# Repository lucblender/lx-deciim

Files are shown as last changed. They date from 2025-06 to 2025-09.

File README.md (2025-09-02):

# lx-deciim

lx-deciim

The lx-deciim is a unique 2-channel bitcrusher eurorack module. Conventionals bitcrushers reduce resolution of the input bit by bit starting by the LSB (Least Significant Bit).

The lx-deciim let you select which bit you want to disable. In addition, when a bit is disabled, it can be replaced by a CV input going through a trigger to get a clean '0' '1' value.

The trigger compares the input value against the CV to a reference voltate. This ref value can be set to either 0V or 2.5V from a jumper on the back of the module. In addition, you can also downsample the input signal.

The module is based on the Daisy Seed by Electrosmith.

## Concept

The concept of the module can be described by the following equation:

`audioOut = (audioIn & ~concatSwitch) + (concatTrigger & concatSwitch)`

Considering:

- `audioOut` : 12 bits binary audio output in (integer)
- `audioIn` : 12 bits binary audio input in (integer)
- `concatSwitch` : 12 bits binary value of the concatenation of the switches' value
- `concatTrigger` : 12 bits binary value of the concatenation of the input trigger value

## Bloc diagram

Bloc diagram

## Specification

- 12 bits 48kHz
- 12 CVs input to trigger audio-rate capable
- 2 inputs eurack level compatible +-5V
- 2 outputs eurack level compatible +-5V
- Downsampling from 48kHz to 1kHz
- Width: 12HP
- Power Consumptions +12V=80mA, -12V=2mA, +5V=0mA

## Repository content

- [Hardware](Hardware/): KiCad Project & Front Panel
  - [Hardware/lx-deciim/](Hardware/lx-deciim/): KiCad Project, Main PCB + Front Panel PCB
  - [Hardware/lx-deciim-front-panel/](Hardware/lx-deciim-front-panel/): SVG design of the front panel
- [Software](Software/): Main software & python script to generate front panel design
  - [Software/lx-deciim-libdaisy/](Software/lx-deciim-libdaisy/): Main software based on LibDaisy
  - [pattern_square_generator.py](Software/pattern_square_generator.py): Main software & python script to generate front panel design

## Hardware

The module consist of 2 PCBs. The main PCB (in reality two PCBs on a panel), and the front panel. The main PCB is really standard 2 layers PCB. After snapping the panel, you can assemble the two PCBs together with the help of male/female header. The front panel is a one layer PCB. I chose matte black solder mask, white silkscreen and ENIG finish on the copper.

All PCB shown in pictures in this repo are manufactured using [PCBWay](https://pcbway.com) services.

PCBWay provides high-quality PCB manufacturing with reliable service and fast turnaround times, making them my first choice for prototyping as seen in this project. They can also make more complex PCB to fit any of your requirements.

## License

This project is licensed under the [CC BY-NC 4.0](https://creativecommons.org/licenses/by-nc/4.0/) License. You may use, modify, and share it for non-commercial purposes.

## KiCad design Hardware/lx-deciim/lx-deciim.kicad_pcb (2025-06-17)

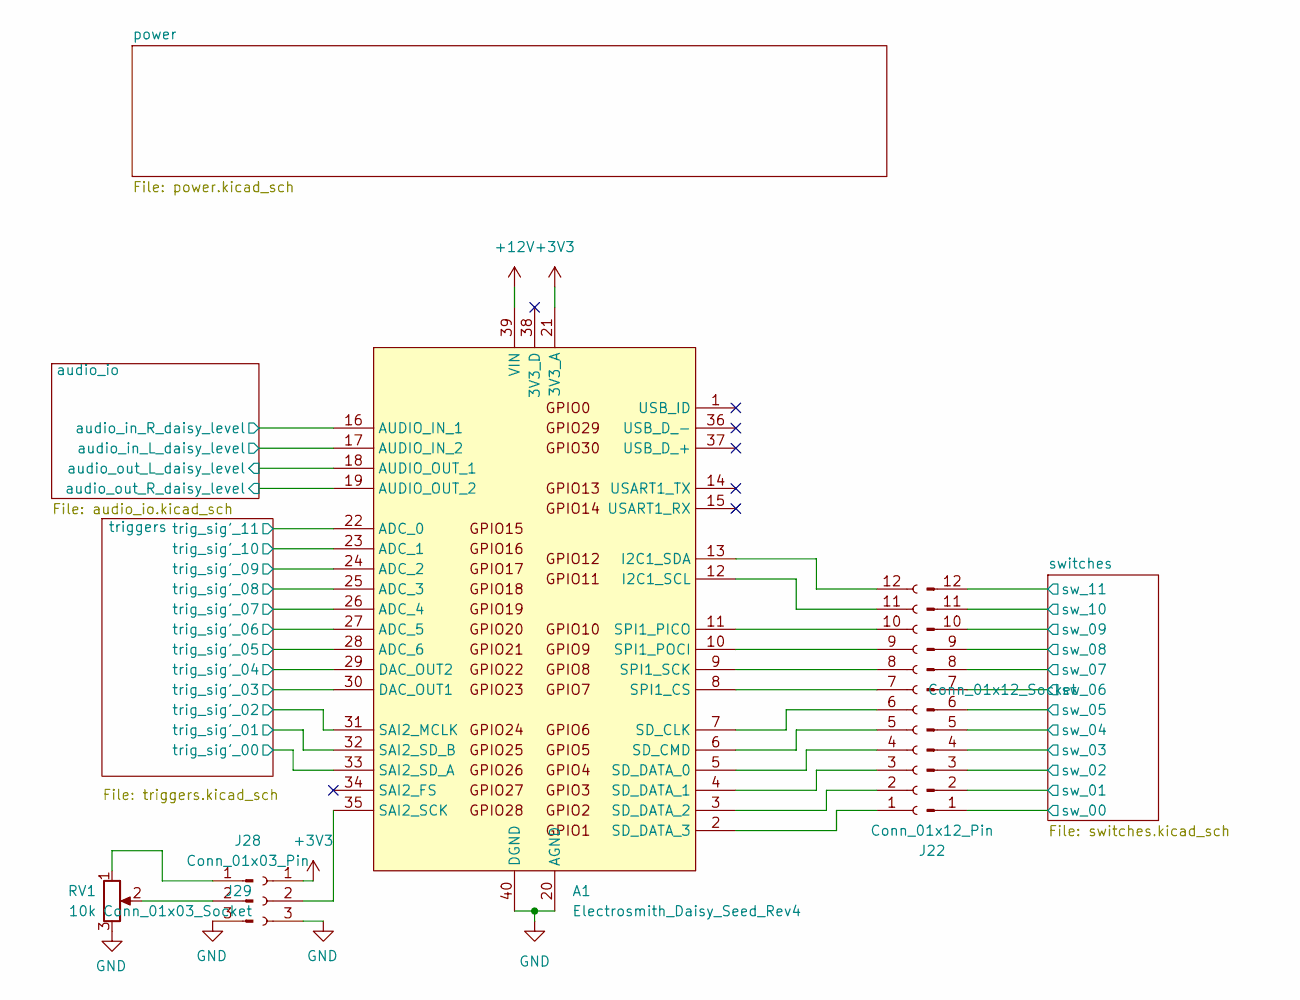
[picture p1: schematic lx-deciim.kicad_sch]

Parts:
A1: Electrosmith_Daisy_Seed_Rev4; Electrosmith_Daisy_Seed
J22: Conn_01x12_Pin; PinHeader_1x12_P2.54mm_Vertical
J23: Conn_01x12_Socket; PinSocket_1x12_P2.54mm_Vertical
J28: Conn_01x03_Pin; PinHeader_1x03_P2.54mm_Vertical
J29: Conn_01x03_Socket; PinSocket_1x03_P2.54mm_Vertical
RV1: 10k; Potentiometer_Alpha_RD901F-40-00D_Single_Vertical; Mouser Part Number 311-1940F-15F-B10K

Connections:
+3V3: A1.21 (3V3_A), J29.1
+12V: A1.39 (VIN); also elsewhere on the board
/audio_io/audio_in_L_daisy_level: A1.17 (AUDIO_IN_2); also elsewhere on the board
/audio_io/audio_in_R_daisy_level: A1.16 (AUDIO_IN_1); also elsewhere on the board
/audio_io/audio_out_L_daisy_level: A1.18 (AUDIO_OUT_1); also elsewhere on the board
/audio_io/audio_out_R_daisy_level: A1.19 (AUDIO_OUT_2); also elsewhere on the board
/switches/sw_00: J22.1; also elsewhere on the board
/switches/sw_01: J22.2; also elsewhere on the board
/switches/sw_02: J22.3; also elsewhere on the board
/switches/sw_03: J22.4; also elsewhere on the board
/switches/sw_04: J22.5; also elsewhere on the board
/switches/sw_05: J22.6; also elsewhere on the board
/switches/sw_06: J22.7; also elsewhere on the board
/switches/sw_07: J22.8; also elsewhere on the board
/switches/sw_08: J22.9; also elsewhere on the board
/switches/sw_09: J22.10; also elsewhere on the board
/switches/sw_10: J22.11; also elsewhere on the board
/switches/sw_11: J22.12; also elsewhere on the board
GND: A1.20 (AGND), A1.40 (DGND), J28.3, J29.3, RV1.3; also elsewhere on the board
unnamed: A1.12 (I2C1_SCL), J23.11
unnamed: A1.13 (I2C1_SDA), J23.12
unnamed: A1.35 (SAI2_SCK), J29.2
unnamed: A1.7 (SD_CLK), J23.6
unnamed: A1.6 (SD_CMD), J23.5
unnamed: A1.5 (SD_DATA_0), J23.4
unnamed: A1.4 (SD_DATA_1), J23.3
unnamed: A1.3 (SD_DATA_2), J23.2
unnamed: A1.2 (SD_DATA_3), J23.1
unnamed: A1.8 (SPI1_CS), J23.7
unnamed: A1.11 (SPI1_PICO), J23.10
unnamed: A1.10 (SPI1_POCI), J23.9
unnamed: A1.9 (SPI1_SCK), J23.8
unnamed: J28.1, RV1.1
unnamed: J28.2, RV1.2
trig_sig'_00: A1.33 (SAI2_SD_A); also elsewhere on the board
trig_sig'_01: A1.32 (SAI2_SD_B); also elsewhere on the board
trig_sig'_02: A1.31 (SAI2_MCLK); also elsewhere on the board
trig_sig'_03: A1.30 (DAC_OUT1); also elsewhere on the board
trig_sig'_04: A1.29 (DAC_OUT2); also elsewhere on the board
trig_sig'_05: A1.28 (ADC_6); also elsewhere on the board
trig_sig'_06: A1.27 (ADC_5); also elsewhere on the board
trig_sig'_07: A1.26 (ADC_4); also elsewhere on the board
trig_sig'_08: A1.25 (ADC_3); also elsewhere on the board
trig_sig'_09: A1.24 (ADC_2); also elsewhere on the board
trig_sig'_10: A1.23 (ADC_1); also elsewhere on the board
trig_sig'_11: A1.22 (ADC_0); also elsewhere on the board

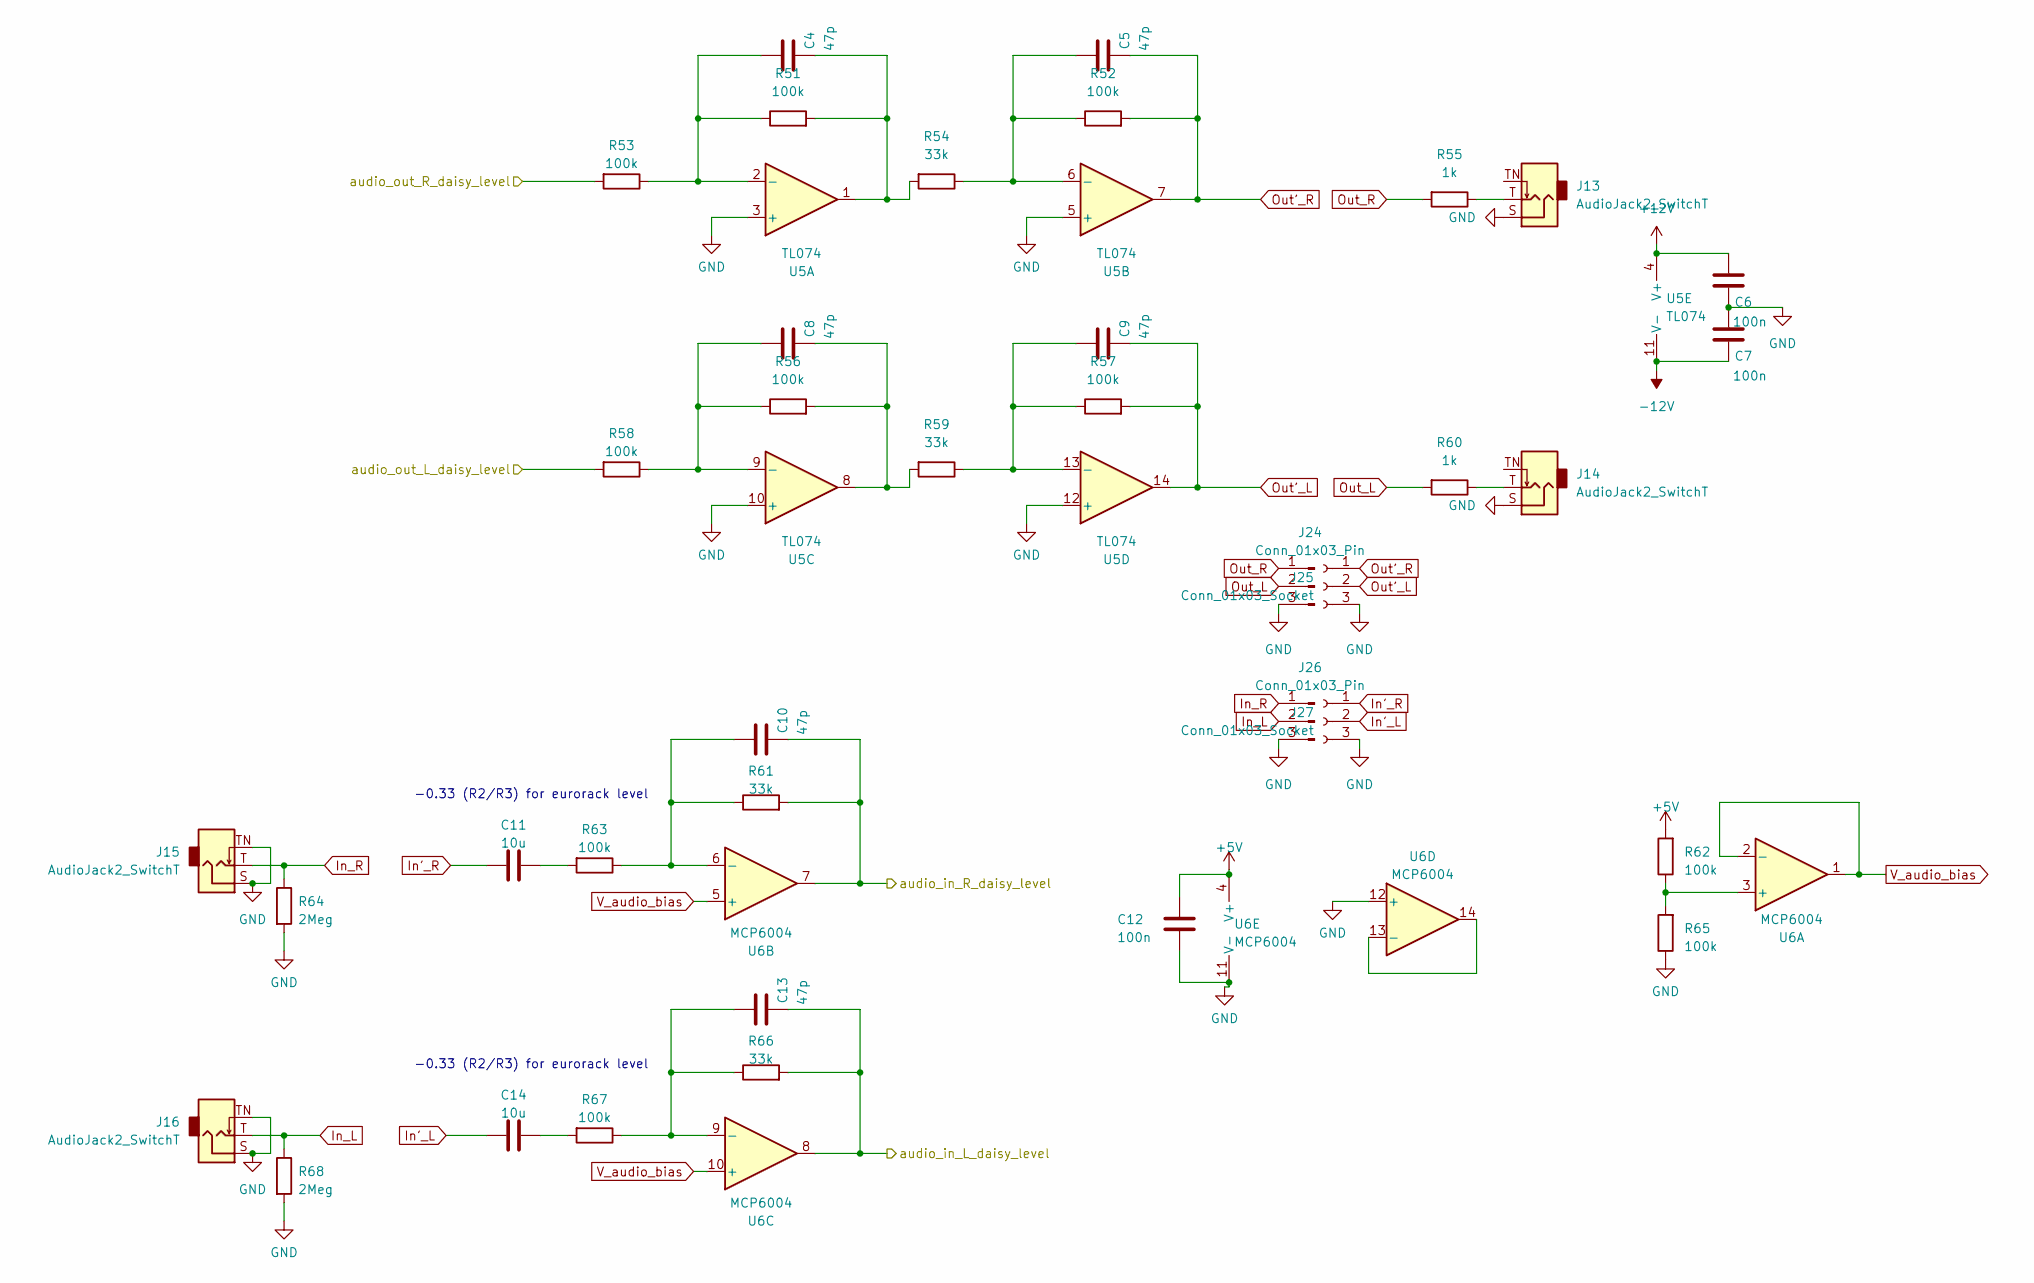
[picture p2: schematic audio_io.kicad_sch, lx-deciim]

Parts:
C4, C5, C8, C9, C10, C13: 47p; C_0603_1608Metric; Mouser Part Number 77-VJ0603A470KXJCBC
C6, C7, C12: 100n; C_0603_1608Metric; Mouser Part Number 710-885012206071R
C11, C14: 10u; C_0603_1608Metric; Mouser Part Number 963-BASE168SB5105KT
J13, J14, J15, J16: AudioJack2_SwitchT; PJ301M-12
J24, J26: Conn_01x03_Pin; PinHeader_1x03_P2.54mm_Vertical
J25, J27: Conn_01x03_Socket; PinSocket_1x03_P2.54mm_Vertical
R51, R52, R53, R56, R57, R58, R62, R63, R65, R67: 100k; R_0603_1608Metric; Mouser Part Number 603-AC0603JR-07100KL
R54, R59, R61, R66: 33k; R_0603_1608Metric; Mouser Part Number 660-RK73H1JTTD3302F
R55, R60: 1k; R_0603_1608Metric; Mouser Part Number 660-RK73H1JTTD1001F
R64, R68: 2Meg; R_0603_1608Metric; Mouser Part Number 660-RK73H1JTTDD2004F
U5: TL074; SOP50P326X110-14N; Mouser Part Number 595-TL074HIDYYR
U6: MCP6004; SOIC-14_3.9x8.7mm_P1.27mm; Mouser Part Number 579-MCP6004-I/SL

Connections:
+5V: C12.1, R62.2, U6.4 (V+); also elsewhere on the board
+12V: C6.1, U5.4 (V+); also elsewhere on the board
-12V: C7.2, U5.11 (V-); also elsewhere on the board
/audio_io/audio_in_L_daisy_level: C13.2, R66.2, U6.8; also elsewhere on the board
/audio_io/audio_in_R_daisy_level: C10.2, R61.2, U6.7; also elsewhere on the board
/audio_io/audio_out_L_daisy_level: R58.2; also elsewhere on the board
/audio_io/audio_out_R_daisy_level: R53.2; also elsewhere on the board
GND: C6.2, C7.1, C12.2, J13.S, J14.S, J15.S, J15.TN, J16.S, J16.TN, J24.3, J25.3, J26.3, J27.3, R64.2, R65.1, R68.2, U5.3 (+), U5.5 (+), U5.10 (+), U5.12 (+), U6.11 (V-), U6.12 (+); also elsewhere on the board
In'_L: C14.1, J27.2
In'_R: C11.1, J27.1
In_L: J16.T, J26.2, R68.1
In_R: J15.T, J26.1, R64.1
unnamed: C4.2, R51.2, R54.2, U5.1
unnamed: C8.2, R56.2, R59.2, U5.8
unnamed: C11.2, R63.2
unnamed: C14.2, R67.2
unnamed: J13.T, R55.1
unnamed: J14.T, R60.1
unnamed: C4.1, R51.1, R53.1, U5.2 (-)
unnamed: C5.1, R52.1, R54.1, U5.6 (-)
unnamed: C8.1, R56.1, R58.1, U5.9 (-)
unnamed: C9.1, R57.1, R59.1, U5.13 (-)
unnamed: R62.1, R65.2, U6.3 (+)
unnamed: C10.1, R61.1, R63.1, U6.6 (-)
unnamed: C13.1, R66.1, R67.1, U6.9 (-)
unnamed: U6.13 (-), U6.14
Out'_L: C9.2, J25.2, R57.2, U5.14
Out'_R: C5.2, J25.1, R52.2, U5.7
Out_L: J24.2, R60.2
Out_R: J24.1, R55.2
V_audio_bias: U6.1, U6.2 (-), U6.5 (+), U6.10 (+)

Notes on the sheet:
-0.33 (R2/R3) for eurorack level

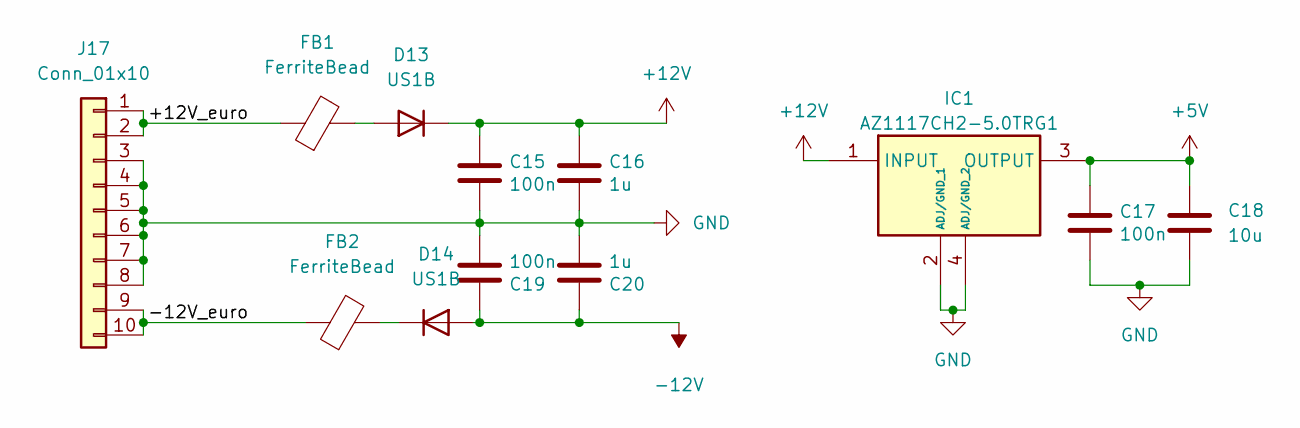
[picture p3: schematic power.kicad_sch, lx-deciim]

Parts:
C15, C17, C19: 100n; C_0603_1608Metric; Mouser Part Number 710-885012206071R; LCSC C14663
C16, C20: 1u; C_0603_1608Metric; Mouser Part Number 187-CL10B105KO8NNWC; LCSC C14663
C18: 10u; C_0603_1608Metric; Mouser Part Number 963-BASE168SB5105KT
D13, D14: US1B; D_SMA; Mouser Part Number 637-US1B
FB1, FB2: FerriteBead; L_0805_2012Metric; Mouser Part Number 710-742792031
IC1: AZ1117CH2-5.0TRG1; SOT230P700X180-4N; Mouser Part Number 621-AZ1117CH2-5.0TRG
J17: Conn_01x10; PinHeader_2x05_P2.54mm_Vertical_SMD; Mouser Part Number 200-TSM10501LDVPTR

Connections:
+5V: C17.1, C18.2, IC1.3 (OUTPUT); also elsewhere on the board
+12V: C15.1, C16.1, D13.1 (K), IC1.1 (INPUT); also elsewhere on the board
-12V: C19.1, C20.1, D14.2 (A); also elsewhere on the board
/power/+12V_euro: FB1.1, J17.1, J17.2
/power/-12V_euro: FB2.1, J17.9, J17.10
GND: C15.2, C16.2, C17.2, C18.1, C19.2, C20.2, IC1.2 (ADJ/GND_1), IC1.4 (ADJ/GND_2), J17.3, J17.4, J17.5, J17.6, J17.7, J17.8; also elsewhere on the board
unnamed: D13.2 (A), FB1.2
unnamed: D14.1 (K), FB2.2

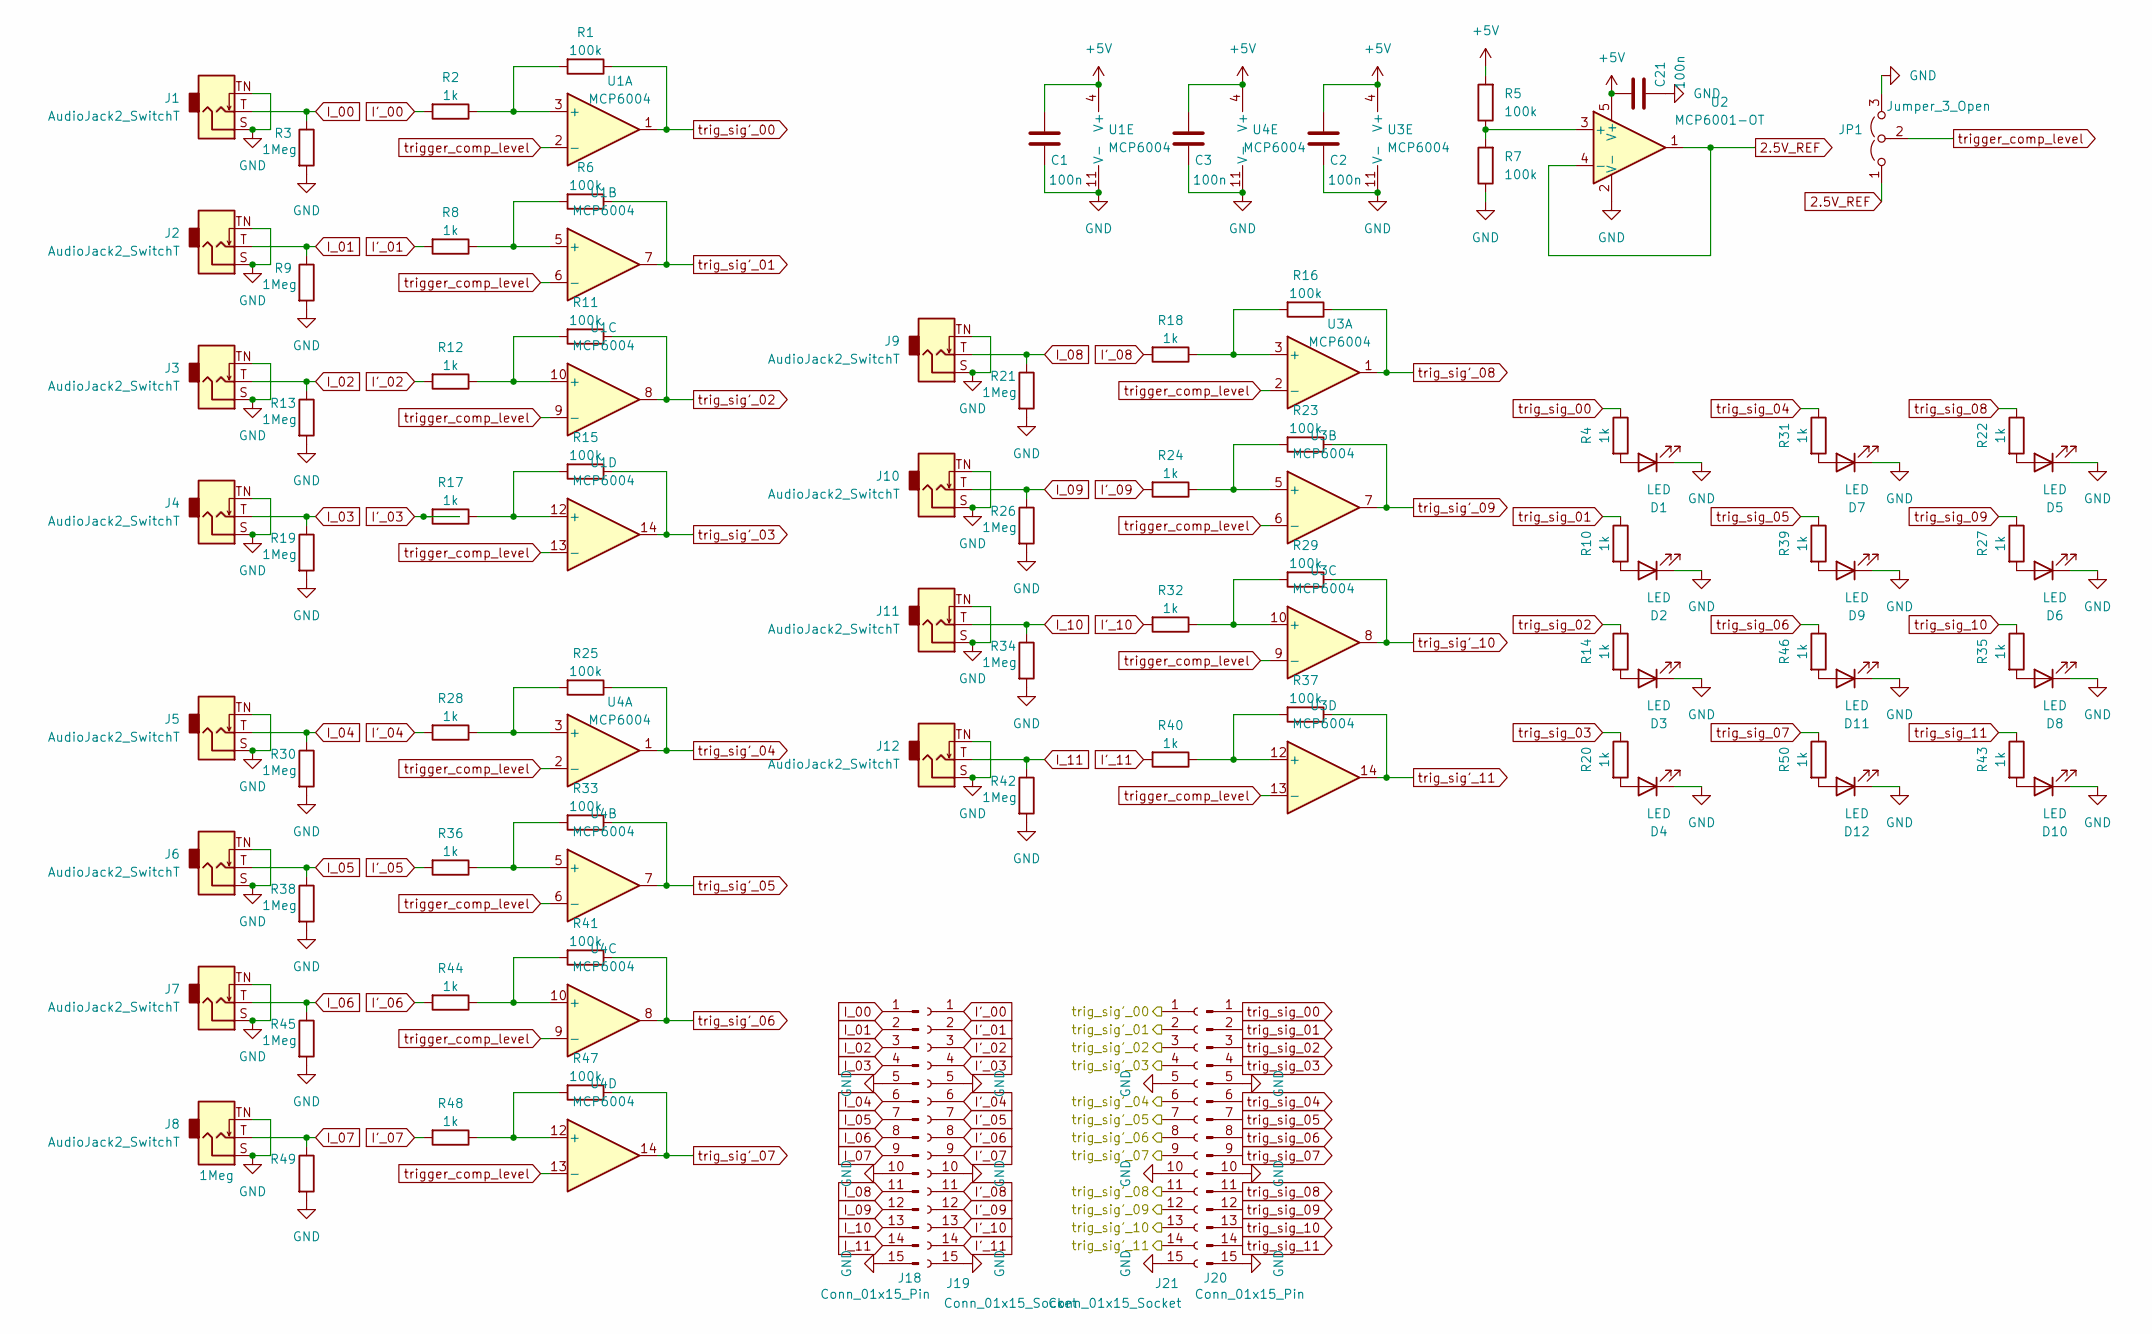
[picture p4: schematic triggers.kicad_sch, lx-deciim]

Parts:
C1, C2, C3, C21: 100n; C_0603_1608Metric; Mouser Part Number 710-885012206071R
D1, D2, D3, D4, D5, D6, D7, D8, D9, D10, D11, D12: LED; LED_D3.0mm; Mouser Part Number 859-LTL1CHTBK5
J1, J2, J3, J4, J5, J6, J7, J8, J9, J10, J11, J12: AudioJack2_SwitchT; PJ301M-12
J18, J20: Conn_01x15_Pin; PinHeader_1x15_P2.54mm_Vertical; Mouser Part Number 737-PH1-40-UA
J19, J21: Conn_01x15_Socket; PinSocket_1x15_P2.54mm_Vertical; Mouser Part Number 737-SMC-1-40-1-GT
JP1: Jumper_3_Open; PinHeader_1x03_P2.54mm_Vertical; Mouser Part Number 737-MSA-G
R1, R5, R6, R7, R11, R15, R16, R23, R25, R29, R33, R37, R41, R47: 100k; R_0603_1608Metric; Mouser Part Number 603-AC0603JR-07100KL
R2, R4, R8, R10, R12, R14, R17, R18, R20, R22, R24, R27, R28, R31, R32, R35, R36, R39, R40, R43, R44, R46, R48, R50: 1k; R_0603_1608Metric; Mouser Part Number 660-RK73H1JTTD1001F
R3, R9, R13, R19, R21, R26, R30, R34, R38, R42, R45, R49: 1Meg; R_0603_1608Metric; Mouser Part Number 71-CRCW0603-1.0M-E3
U1, U3, U4: MCP6004; SOIC-14_3.9x8.7mm_P1.27mm; Mouser Part Number 579-MCP6004-I/SL
U2: MCP6001-OT; SOT-23-5; Mouser Part Number 579-MCP6001RT-I/OT

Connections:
2.5V_REF: JP1.1 (A), U2.1, U2.4 (-)
+5V: C1.1, C2.1, C3.1, C21.1, R5.2, U1.4 (V+), U2.5 (V+), U3.4 (V+), U4.4 (V+); also elsewhere on the board
GND: C1.2, C2.2, C3.2, C21.2, D1.1 (K), D2.1 (K), D3.1 (K), D4.1 (K), D5.1 (K), D6.1 (K), D7.1 (K), D8.1 (K), D9.1 (K), D10.1 (K), D11.1 (K), D12.1 (K), J1.S, J1.TN, J2.S, J2.TN, J3.S, J3.TN, J4.S, J4.TN, J5.S, J5.TN, J6.S, J6.TN, J7.S, J7.TN, J8.S, J8.TN, J9.S, J9.TN, J10.S, J10.TN, J11.S, J11.TN, J12.S, J12.TN, J18.5, J18.10, J18.15, J19.5, J19.10, J19.15, J20.5, J20.10, J20.15, J21.5, J21.10, J21.15, JP1.3 (B), R3.2, R7.1, R9.2, R13.2, R19.2, R21.2, R26.2, R30.2, R34.2, R38.2, R42.2, R45.2, R49.2, U1.11 (V-), U2.2 (V-), U3.11 (V-), U4.11 (V-); also elsewhere on the board
I'_00: J19.1, R2.2
I'_01: J19.2, R8.2
I'_02: J19.3, R12.2
I'_03: J19.4, R17.2
I'_04: J19.6, R28.2
I'_05: J19.7, R36.2
I'_06: J19.8, R44.2
I'_07: J19.9, R48.2
I'_08: J19.11, R18.2
I'_09: J19.12, R24.2
I'_10: J19.13, R32.2
I'_11: J19.14, R40.2
I_00: J1.T, J18.1, R3.1
I_01: J2.T, J18.2, R9.1
I_02: J3.T, J18.3, R13.1
I_03: J4.T, J18.4, R19.1
I_04: J5.T, J18.6, R30.1
I_05: J6.T, J18.7, R38.1
I_06: J7.T, J18.8, R45.1
I_07: J8.T, J18.9, R49.1
I_08: J9.T, J18.11, R21.1
I_09: J10.T, J18.12, R26.1
I_10: J11.T, J18.13, R34.1
I_11: J12.T, J18.14, R42.1
unnamed: D1.2 (A), R4.2
unnamed: D2.2 (A), R10.2
unnamed: D3.2 (A), R14.2
unnamed: D4.2 (A), R20.2
unnamed: D5.2 (A), R22.2
unnamed: D6.2 (A), R27.2
unnamed: D7.2 (A), R31.2
unnamed: D8.2 (A), R35.2
unnamed: D9.2 (A), R39.2
unnamed: D10.2 (A), R43.2
unnamed: D11.2 (A), R46.2
unnamed: D12.2 (A), R50.2
unnamed: R1.2, R2.1, U1.3 (+)
unnamed: R6.2, R8.1, U1.5 (+)
unnamed: R11.2, R12.1, U1.10 (+)
unnamed: R15.2, R17.1, U1.12 (+)
unnamed: R5.1, R7.2, U2.3 (+)
unnamed: R16.2, R18.1, U3.3 (+)
unnamed: R23.2, R24.1, U3.5 (+)
unnamed: R29.2, R32.1, U3.10 (+)
unnamed: R37.2, R40.1, U3.12 (+)
unnamed: R25.2, R28.1, U4.3 (+)
unnamed: R33.2, R36.1, U4.5 (+)
unnamed: R41.2, R44.1, U4.10 (+)
unnamed: R47.2, R48.1, U4.12 (+)
trig_sig'_00: J21.1, R1.1, U1.1; also elsewhere on the board
trig_sig'_01: J21.2, R6.1, U1.7; also elsewhere on the board
trig_sig'_02: J21.3, R11.1, U1.8; also elsewhere on the board
trig_sig'_03: J21.4, R15.1, U1.14; also elsewhere on the board
trig_sig'_04: J21.6, R25.1, U4.1; also elsewhere on the board
trig_sig'_05: J21.7, R33.1, U4.7; also elsewhere on the board
trig_sig'_06: J21.8, R41.1, U4.8; also elsewhere on the board
trig_sig'_07: J21.9, R47.1, U4.14; also elsewhere on the board
trig_sig'_08: J21.11, R16.1, U3.1; also elsewhere on the board
trig_sig'_09: J21.12, R23.1, U3.7; also elsewhere on the board
trig_sig'_10: J21.13, R29.1, U3.8; also elsewhere on the board
trig_sig'_11: J21.14, R37.1, U3.14; also elsewhere on the board
trig_sig_00: J20.1, R4.1
trig_sig_01: J20.2, R10.1
trig_sig_02: J20.3, R14.1
trig_sig_03: J20.4, R20.1
trig_sig_04: J20.6, R31.1
trig_sig_05: J20.7, R39.1
trig_sig_06: J20.8, R46.1
trig_sig_07: J20.9, R50.1
trig_sig_08: J20.11, R22.1
trig_sig_09: J20.12, R27.1
trig_sig_10: J20.13, R35.1
trig_sig_11: J20.14, R43.1
trigger_comp_level: JP1.2 (C), U1.2 (-), U1.6 (-), U1.9 (-), U1.13 (-), U3.2 (-), U3.6 (-), U3.9 (-), U3.13 (-), U4.2 (-), U4.6 (-), U4.9 (-), U4.13 (-)

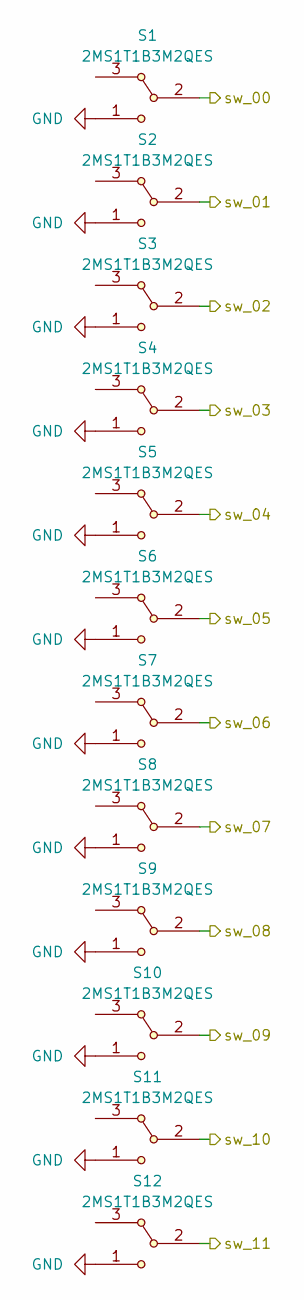
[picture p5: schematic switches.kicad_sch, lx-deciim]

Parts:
S1, S2, S3, S4, S5, S6, S7, S8, S9, S10, S11, S12: 2MS1T1B3M2QES; Mouser Part Number 118-2MS1T1B3M2QES

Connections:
/switches/sw_00: S1.2; also elsewhere on the board
/switches/sw_01: S2.2; also elsewhere on the board
/switches/sw_02: S3.2; also elsewhere on the board
/switches/sw_03: S4.2; also elsewhere on the board
/switches/sw_04: S5.2; also elsewhere on the board
/switches/sw_05: S6.2; also elsewhere on the board
/switches/sw_06: S7.2; also elsewhere on the board
/switches/sw_07: S8.2; also elsewhere on the board
/switches/sw_08: S9.2; also elsewhere on the board
/switches/sw_09: S10.2; also elsewhere on the board
/switches/sw_10: S11.2; also elsewhere on the board
/switches/sw_11: S12.2; also elsewhere on the board
GND: S1.1, S2.1, S3.1, S4.1, S5.1, S6.1, S7.1, S8.1, S9.1, S10.1, S11.1, S12.1; also elsewhere on the board

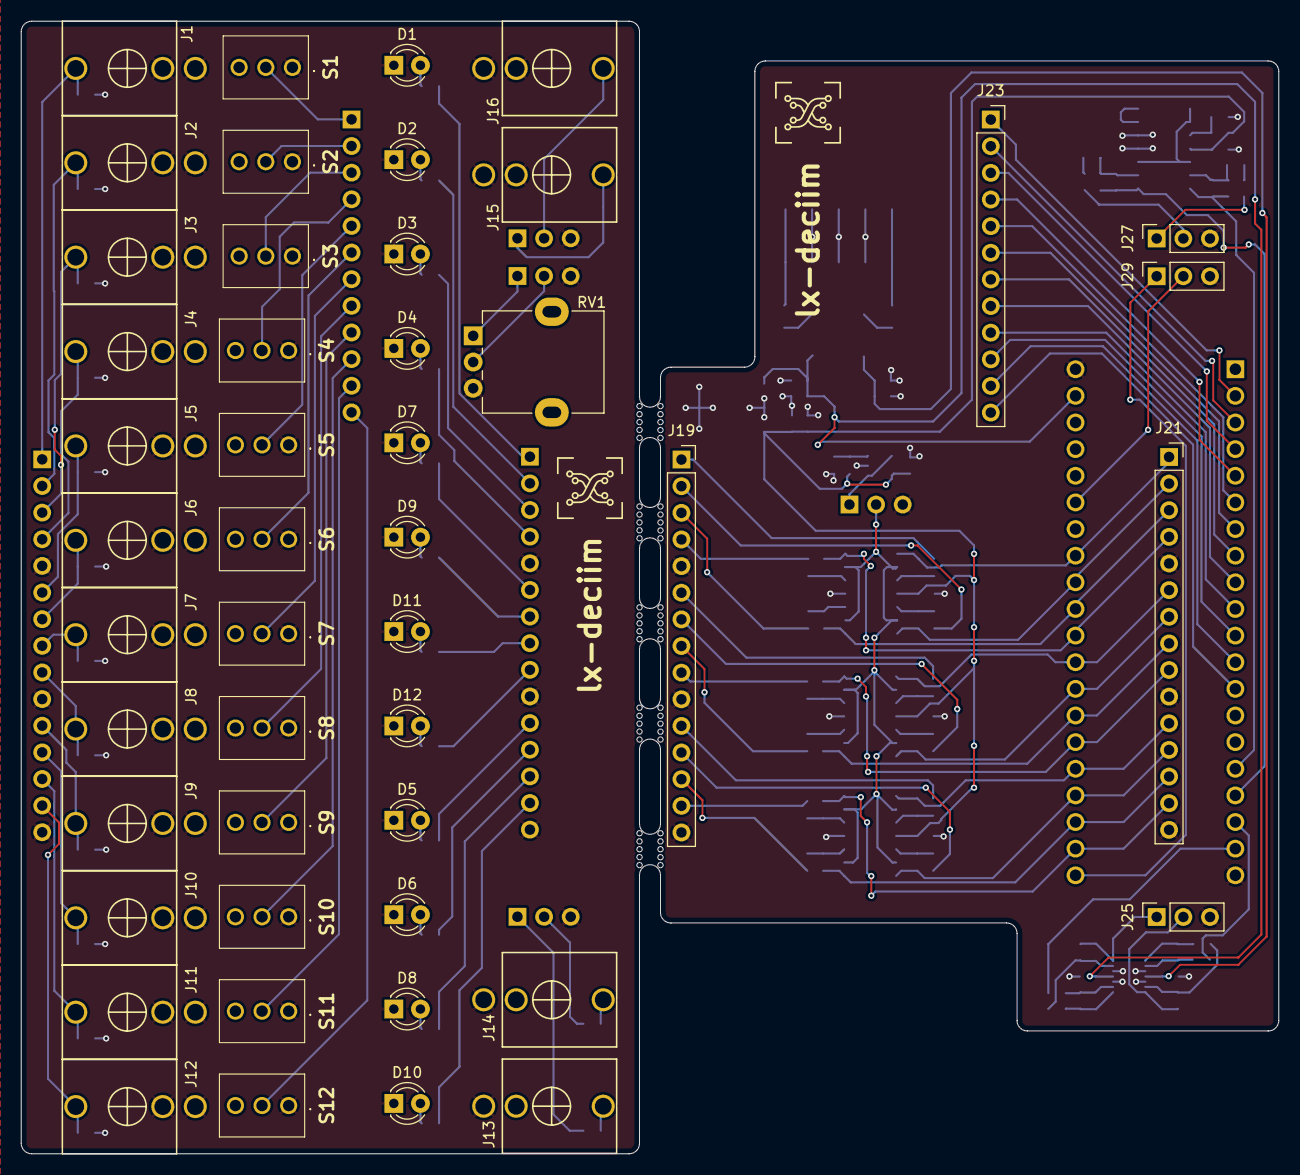
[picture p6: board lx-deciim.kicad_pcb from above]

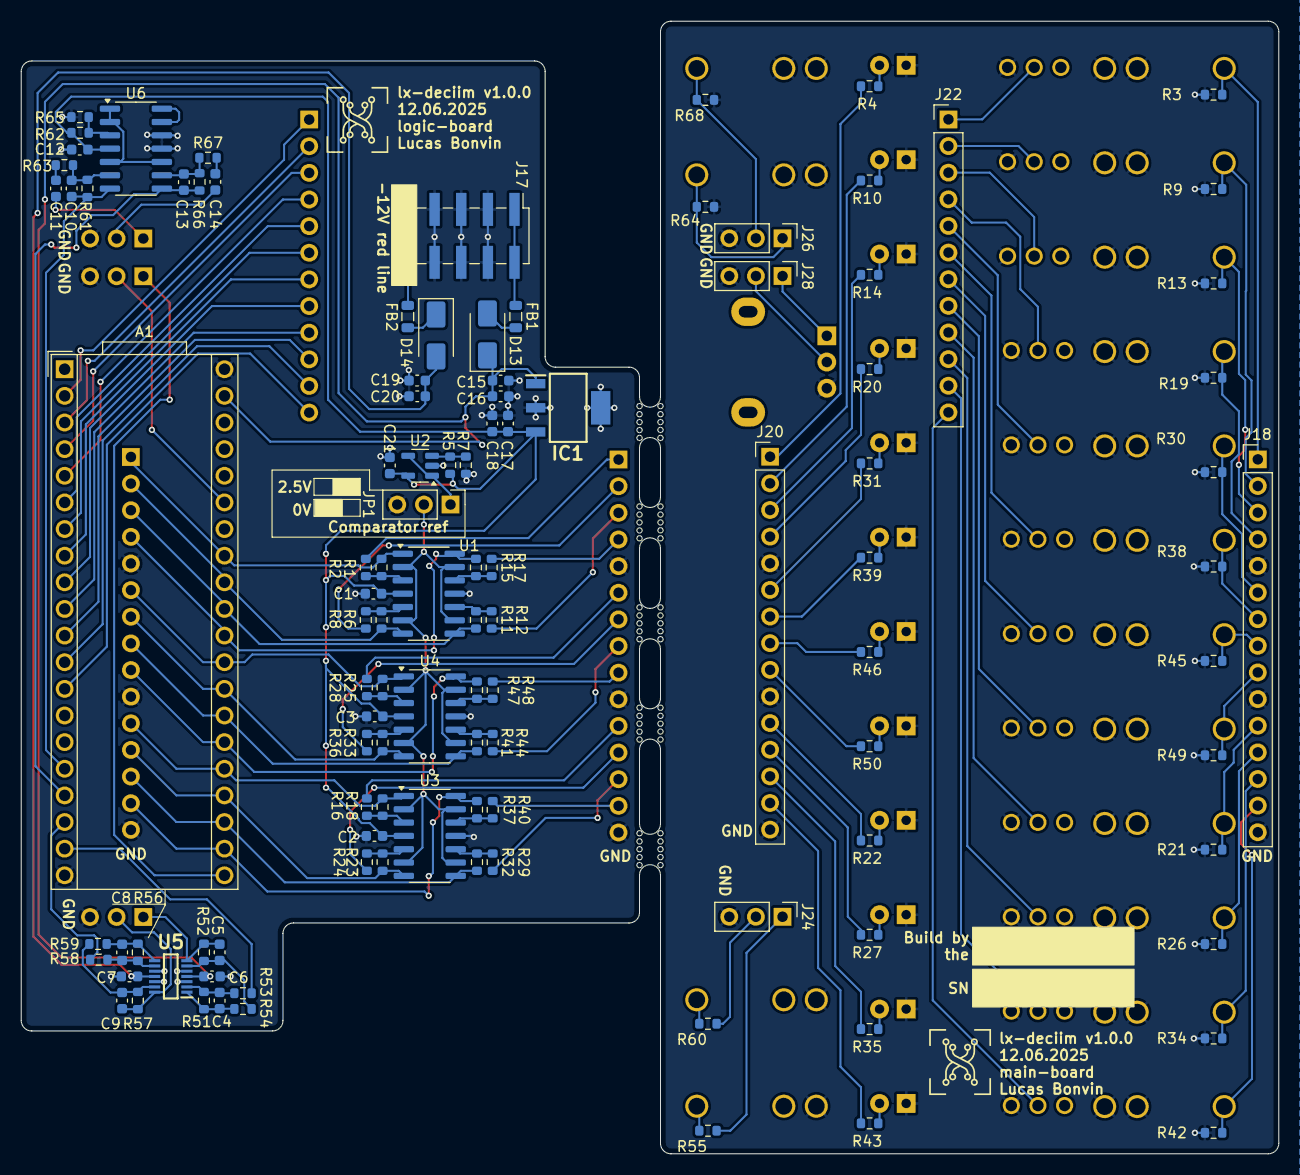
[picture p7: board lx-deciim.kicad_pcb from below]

Board: 2 copper layers, 119.9 x 108.0 mm, 156 parts (109 on the bottom side), 138 nets.

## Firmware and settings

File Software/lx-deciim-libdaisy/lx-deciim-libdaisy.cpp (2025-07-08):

#include "daisy_seed.h"
#include "inc/DownSampler.h"

using namespace daisy;

#define N_BITS 12
#define MAX_DOWNSAMPLE_FREQ 1000.0f

// uncomment for debug gpios
// #define DEBUG_ANALOG
// #define DEBUG_DIGITAL

float downSamplingIndex = 1.0f;

#define DOWN_SAMPLE_AC seed::A11

daisy::Pin triggerPins[12] = {
    seed::D15, // LSB
    seed::D16,
    seed::D17,
    seed::D18,
    seed::D19,
    seed::D20,
    seed::D21,
    seed::D22,
    seed::D23,
    seed::D24,
    seed::D25,
    seed::D26 // MSB
};
GPIO triggerGPIOs[12] = {GPIO(), GPIO(), GPIO(), GPIO(), GPIO(), GPIO(), GPIO(), GPIO(), GPIO(), GPIO(), GPIO(), GPIO()};
daisy::Pin switchPins[12] = {
    seed::D12, // LSB
    seed::D11,
    seed::D10,
    seed::D9,
    seed::D8,
    seed::D7,
    seed::D6,
    seed::D5,
    seed::D4,
    seed::D3,
    seed::D2,
    seed::D1 // MSB
};
GPIO switchGPIOs[12] = {GPIO(), GPIO(), GPIO(), GPIO(), GPIO(), GPIO(), GPIO(), GPIO(), GPIO(), GPIO(), GPIO(), GPIO()};

uint16_t concatTrigger = 0;
uint16_t concatSwitch = 0;

AdcChannelConfig downSampleAn = AdcChannelConfig();

DownSampler downSampler0 = DownSampler();
DownSampler downSampler1 = DownSampler();

/** Global Hardware access */
DaisySeed hw;

float sample_rate;

float bitCrush(float in);
void readAnalogs();
void readDigitals();

void AudioCallback(AudioHandle::InterleavingInputBuffer in,
                   AudioHandle::InterleavingOutputBuffer out,
                   size_t size)
{
    // when not in debug (analog or digital), read them in the AudioCallback
#ifndef DEBUG_ANALOG
    readAnalogs();
#endif
    downSampler0.setDownSamplingFactor(downSamplingIndex);
    downSampler1.setDownSamplingFactor(downSamplingIndex);

    for (size_t i = 0; i < size; i += 2)
    {
        // when not in debug (analog or digital), read them in the AudioCallback
#ifndef DEBUG_DIGITAL
        readDigitals();
#endif
        out[i] = downSampler1.Process(bitCrush(in[i + 1]));
        out[i + 1] = downSampler0.Process(bitCrush(in[i]));
    }
}

int main(void)
{
    /** Initialize our hardware */
    hw.Init();
    hw.SetAudioBlockSize(48);

    // How many samples we'll output per second
    sample_rate = hw.AudioSampleRate();

    hw.StartLog();

    downSampleAn.InitSingle(DOWN_SAMPLE_AC);
    AdcChannelConfig adcChannelConfigs[] = {downSampleAn};

    hw.adc.Init(adcChannelConfigs, 1);
    hw.adc.Start();

    // funky blinking led boot sequence
    for (int i = 0; i < 12; i++)
    {
        triggerGPIOs[i].Init(triggerPins[i], GPIO::Mode::OUTPUT);
        triggerGPIOs[i].Write(0);
    }
    for (int i = 0; i < 12; i++)
    {
        triggerGPIOs[i].Write(1);
        hw.DelayMs(50);
    }
    for (int i = 0; i < 12; i++)
    {
        triggerGPIOs[i].Write(0);
        hw.DelayMs(50);
    }

    // triggers pin, input, no pull up/down
    for (int i = 0; i < 12; i++)
    {
        triggerGPIOs[i].Init(triggerPins[i], GPIO::Mode::INPUT);
    }

    // switch pin, input, pull up
    for (int i = 0; i < 12; i++)
    {
        switchGPIOs[i].Init(switchPins[i], GPIO::Mode::INPUT, GPIO::Pull::PULLUP, GPIO::Speed::LOW);
    }

    hw.StartAudio(AudioCallback);

    /** Infinite Loop */
    while (1)
    {
        // when in debug (analog or digital), read them in the main loop to not overload the serial output
#ifdef DEBUG_ANALOG
        readAnalogs();
        hw.DelayMs(50);
#endif
#ifdef DEBUG_DIGITAL
        readDigitals();
        hw.PrintLine("result for 1.0f %f", bitCrush(1.0f));
        hw.PrintLine("result for -1.0f %f", bitCrush(-1.0f));
        hw.PrintLine("result for 0.5f %f", bitCrush(0.5f));
        hw.PrintLine("result for -0.5f %f", bitCrush(-0.5f));
        hw.PrintLine("result for 0.0f %f", bitCrush(0.0f));
        hw.DelayMs(50);
#endif
    }
}

void readAnalogs()
{
    uint16_t anDownSampling = hw.adc.Get(0);

    float rawDownSamplingIndex = sample_rate / ((anDownSampling / 65536.0f) * (sample_rate - MAX_DOWNSAMPLE_FREQ) + MAX_DOWNSAMPLE_FREQ);
    // do those cast to set get only one decimal
    downSamplingIndex = static_cast<float>(static_cast<int>(rawDownSamplingIndex * 10.)) / 10.;

#ifdef DEBUG_ANALOG
    hw.PrintLine("anDownSampling: %d", anDownSampling);
    hw.PrintLine("downSamplingIndex: %f", downSamplingIndex);
#endif
}

void readDigitals()
{
    bool tmpRead = 0;
    uint16_t tmpConcatSwitch = 0;
    uint16_t tmpConcatTrigger = 0;
#ifdef DEBUG_DIGITAL
    hw.Print("switchGPIOs:\t");
#endif
    for (int i = 11; i >= 0; i--) // do from 11 to 0 so it's MSB to LSB (just for printing and debug)
    {
        tmpRead = switchGPIOs[i].Read();
        /* This turn off the leds when switches are set to off, this sadly cause problems with the triggers
        if (tmpRead == 0)
        {
            triggerGPIOs[i].Init(triggerPins[i], GPIO::Mode::OUTPUT);
            triggerGPIOs[i].Write(0);
        }
        else
            triggerGPIOs[i].Init(triggerPins[i], GPIO::Mode::INPUT);
        */
        tmpConcatSwitch = tmpConcatSwitch + (tmpRead << i);
#ifdef DEBUG_DIGITAL
        hw.Print("%d ", tmpRead);
#endif
    }
    concatSwitch = tmpConcatSwitch;

#ifdef DEBUG_DIGITAL
    hw.PrintLine("-\t concatSwitch:%d", concatSwitch);
    hw.Print("triggerGPIOs:\t");
#endif

    for (int i = 11; i >= 0; i--) // do from 11 to 0 so it's MSB to LSB (just for printing and debug)
    {
        tmpRead = triggerGPIOs[i].Read();
        tmpConcatTrigger = tmpConcatTrigger + (tmpRead << i);
#ifdef DEBUG_DIGITAL
        hw.Print("%d ", tmpRead);
#endif
    }
    concatTrigger = tmpConcatTrigger;
#ifdef DEBUG_DIGITAL
    hw.PrintLine("-\t concatTrigger:%d", concatTrigger);
#endif
}

float bitCrush(float in)
{
    // add a little offset 0f 0.01
    //  if it's 0.5 and there is nothing plugged
    // the float value oscillate a little above and below
    // and so with decimation, it will oscillate between big -1 and +1
    in = in + 0.01; //[-1,1] (plus little offset)

    float dataIn = (in + 1.0f) / 2.0f; //[0,1]

    uint16_t max = (1 << N_BITS) - 1; // 4095
    uint16_t intData = static_cast<uint16_t>(roundf(dataIn * max));

    intData = ((intData & (~concatSwitch)) & max) + ((concatTrigger & concatSwitch) & max);

    // Convert back to float in range [0,1]
    float crushed = static_cast<float>(intData) / max;

    return (crushed * 2.0f) - 1.0f; // return between [-1,1]
}

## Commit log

2025-06-10 feature: add kicad libraries
2025-06-10 feature: first draft of schematic and pcb
    [audio_io.kicad_sch, lx-deciim.kicad_pcb, lx-deciim.kicad_sch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]
2025-06-11 feature: first draft routing
    [audio_io.kicad_sch, lx-deciim.kicad_pcb, lx-deciim.kicad_sch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]
2025-06-12 feature: clean routing
    [lx-deciim.kicad_pcb, triggers.kicad_sch]
2025-06-12 feature: add pattern_square_generator and front pannel
    [lx-deciim-front-panel.kicad_pcb, lx-deciim.kicad_pcb]
2025-06-12 feature: prep files for export (fill bom, gerber)
    [audio_io.kicad_sch, lx-deciim-front-panel.kicad_pcb, lx-deciim.kicad_pcb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]
2025-06-17 fix: fix mouser part number on schematic + fill page settings
    [audio_io.kicad_sch, lx-deciim.kicad_pcb, lx-deciim.kicad_sch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]
2025-07-02 fix: fix some unstabilities
    [lx-deciim-libdaisy.cpp]
2025-07-02 fix: remove unused var
    [lx-deciim-libdaisy.cpp]
2025-07-02 feature: force out of trigger to 0 if switch is disabled to turn off led
2025-07-02 fix: no delay, remove forcing trigger to 0, cause no more reading of it
    [lx-deciim-libdaisy.cpp]
2025-07-03 fix: put read analog in AudioCallback
    [lx-deciim-libdaisy.cpp]
2025-07-03 fix: fix downsampling error when sampleIndex repass to 0
2025-07-08 feature: funky blinking led boot sequence

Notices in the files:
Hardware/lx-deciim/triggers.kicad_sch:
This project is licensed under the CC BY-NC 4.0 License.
